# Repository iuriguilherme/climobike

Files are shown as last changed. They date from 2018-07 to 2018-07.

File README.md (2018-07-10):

ClimoBike
===

ClimoBike é uma central de monitoramento portátil da qualidade do ar e das condições climáticas, adaptável a bicicletas urbanas.  

Foto (recortada) do projeto no festival de tecnologias red bull basement  

---

Toda a documentação está na [wiki](https://op.velivery.com.br/projects/climobike/wiki).  

Projeto original: <https://github.com/smjacques/climobike>  

### Código fonte

Repositório público git:  

* <https://notabug.org/velivery/climobike>  

### Roadmap

<https://op.velivery.com.br/topics/56>

### Versões

v0.1, 2017-10-05 -- sistema de monitoramento da qualidade do ar e das condições climáticas adaptável a bicicletas, <https://github.com/smjacques/climobike>  
v0.2, 2018-06-10 -- ClimoBike + Velivery <https://notabug.org/velivery/climobike>  
v0.2.0.1, 2018-06-30 -- ESP32 Devkit + GPS, sensor de metano, sensor de gases tóxicos, sensor de umidade relativa do ar e temperatura  
v0.2.0.2, 2018-07-07 -- ESP32 Devkit v2 soldado em placa dentro de invólucro de acrílico com GPS, módulo de cartão SD, sensor de metano, sensor de gases tóxicos, sensor de dióxido de carbono, sensor de umidade relativa do ar e temperatura, buzzer, relógio, e sensor de luminosidade   

Licença
---

Copyleft 2017 Saulo Jacques  
Copyleft 2018 Velivery  

### Contribuições

- Saulo Jacques  
- Alisson Claudino  
- Desobediente Civil  

### GPL v3

**Este programa é distribuído na esperança de que possa ser útil,**
**mas SEM NENHUMA GARANTIA; sem uma garantia implícita de ADEQUAÇÃO**  
**a qualquer MERCADO ou APLICAÇÃO EM PARTICULAR. Veja a**  
**Licença Pública Geral GNU para mais detalhes.**  

**Você deve ter recebido uma cópia da Licença Pública Geral GNU junto**  
**com este programa (veja o arquivo LICENSE.md).**  
**Se não, veja <http://www.gnu.org/licenses/>.**

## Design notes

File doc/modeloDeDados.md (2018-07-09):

# Modelo de dados

Este arquivo é um modelo de como os dados devem ser armazenados no cartão SD

## Nomenclatura de arquivos

Para o ClimoBike 0.2.1, o minuto obtido do relógio deve determinar o nome do 
arquivo. Em caso de falha, um novo arquivo deve ser criado. Em caso de sucesso 
e contínua obtenção de dados, a cada hora um novo arquivo deverá ser criado.
Exemplo do sistema de arquivos em um caso onde às 18:17 um climobike foi 
ligado, sendo que às 18:23 aconteceu uma falha com o cartão, o climobike se 
recuperou e continuou gravando, funcionando normalmente até às 23:45 do mesmo 
dia:

    /dados/2018-07-03-18-17.txt
    /dados/2018-07-03-18-23.txt
    /dados/2018-07-03-18-33.txt
    /dados/2018-07-03-19-33.txt
    /dados/2018-07-03-20-33.txt
    /dados/2018-07-03-21-33.txt
    /dados/2018-07-03-22-33.txt
    /dados/2018-07-03-23-33.txt

Para o ClimoBike 0.2.2, desejavelmente a rotação do arquivo deve ser diária. 
Então o mesmo exemplo acima teria o seguinte resultado se ficasse rodando a 
semana toda:

    /dados/2018-07-03-18-17.txt
    /dados/2018-07-03-18-23.txt
    /dados/2018-07-03-18-33.txt
    /dados/2018-07-04-18-33.txt
    /dados/2018-07-05-18-33.txt
    /dados/2018-07-06-18-33.txt
    /dados/2018-07-07-18-33.txt

## Armazenamento

Os dados devem ser gravados em um arquivo no cartão SD conforme o padrão 
supracitado, de linha em linha e em formato de dicionário python de acordo com 
o padrão JSON.
Abaixo um exemplo identado para facilitar a compreensão, mas nos arquivos, 
todos dados devem estar em uma única linha, que deve ser gravada com somente o 
último caractere sendo newline.

    {
      "climobike" : "0.2.0.2",
      "json" : "0.2",
      "datetime" : "2018-07-03 18:00",
      "tmp" : "25.0",
      "hum" : "50.0",
      "ch4" : "4096",
      "tox" : "4096",
      "co2" : "4096",
      "gpsdate" : "2018-07-03 18:00:00:00",
      "gpslat" : "-30.04",
      "gpslng" : "-51.22",
      "gpssat" : "5",
      "gpshdop" : "535",
    }

Como deveria aparecer em um arquivo gravado no cartão microsd, para garantir a
consistência da escrita, leitura, e envio para servidores HTTP remotos,
assumindo uma gravação em arquivo hipotética com intervalo de um minuto:

    {"climobike":"0.2.0.2","json":"0.2","datetime":"2018-07-03 18:00","tmp":"25.0","hum":"50.0","ch4":"4096","tox":"4096","co2":"4096","gpsdate":"2018-07-03 18:00:00:00","gpslat":"-30.04","gpslng":"-51.22","gpssat":"5","gpshdop":"535",}
    {"climobike":"0.2.0.2","json":"0.2","datetime":"2018-07-03 18:01","tmp":"25.1","hum":"49.9","ch4":"4095","tox":"4097","co2":"4098","gpsdate":"2018-07-03 18:01:00:00","gpslat":"-30.04","gpslng":"-51.22","gpssat":"5","gpshdop":"535",}
    {"climobike":"0.2.0.2","json":"0.2","datetime":"2018-07-03 18:02","tmp":"25.4","hum":"49.9","ch4":"4099","tox":"4092","co2":"4094","gpsdate":"2018-07-03 18:02:00:00","gpslat":"-30.04","gpslng":"-51.22","gpssat":"5","gpshdop":"535",}
    {"climobike":"0.2.0.2","json":"0.2","datetime":"2018-07-03 18:03","tmp":"25.5","hum":"50.1","ch4":"4095","tox":"4093","co2":"4088","gpsdate":"2018-07-03 18:03:00:00","gpslat":"-30.04","gpslng":"-51.22","gpssat":"5","gpshdop":"535",}
    {"climobike":"0.2.0.2","json":"0.2","datetime":"2018-07-03 18:04","tmp":"25.4","hum":"50.3","ch4":"4094","tox":"4096","co2":"4090","gpsdate":"2018-07-03 18:04:00:00","gpslat":"-30.04","gpslng":"-51.22","gpssat":"5","gpshdop":"535",}

### Legenda

- "climobike" : String, versão do ClimoBike;
- "json" : String, versão do modelo de dados;
- "datetime" : RTCDateTime, dados do DS1307;
- "tmp" : Float, temperatura em graus Celsius do DHT;
- "hum" : Float, umidade relativa do ar em (formato) do DHT;
- "ch4" : Float, (quantidade) de metano em (formato) do sensor MQ4;
- "tox" : Float, (quantidade) de gases tóxicos em (formato) do sensor MQ135;
- "co2" : Float, (quantidade) de monóxido de carbono em (formato) do sensor MQ7;
- "gpsdate" : Datetime, dados do GPS (modelo);
- "gpslat" : Float, latitude, dados do GPS;
- "gpslng" : Float, longitude, dados do GPS;
- "gpssat" : Int, quantidade de satélites, dados do GPS;
- "gpshdop" : Int, HDOP, dados do GPS;

## API

Todos sistemas que usufruirem dos dados do climobike terão que respeitar o 
formato definido neste documento. Preferivelmente adaptar radicalmente o 
formato somente até a versão de produção do ClimoBike 0.2

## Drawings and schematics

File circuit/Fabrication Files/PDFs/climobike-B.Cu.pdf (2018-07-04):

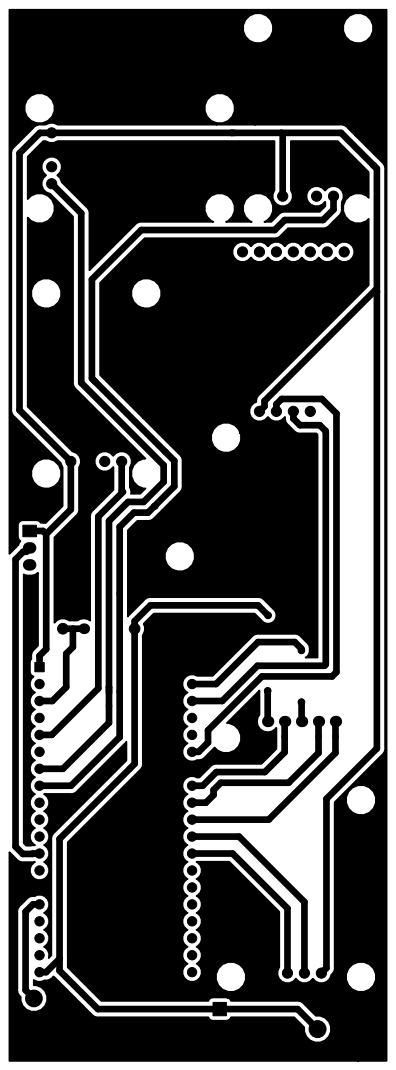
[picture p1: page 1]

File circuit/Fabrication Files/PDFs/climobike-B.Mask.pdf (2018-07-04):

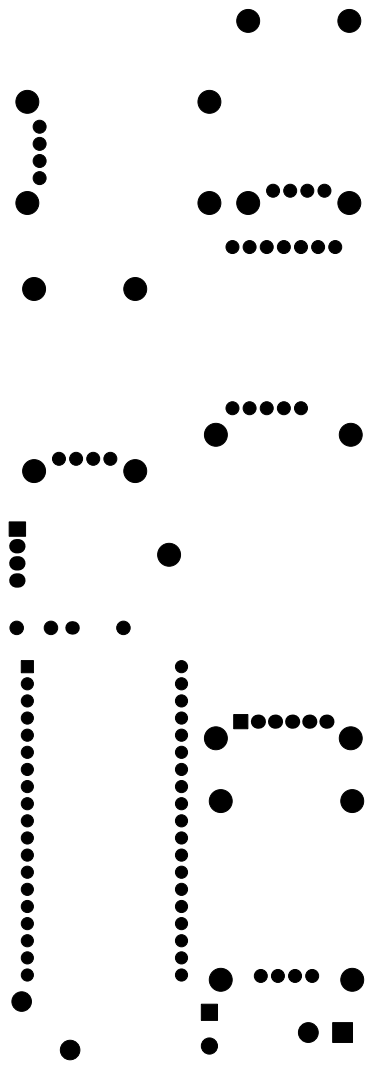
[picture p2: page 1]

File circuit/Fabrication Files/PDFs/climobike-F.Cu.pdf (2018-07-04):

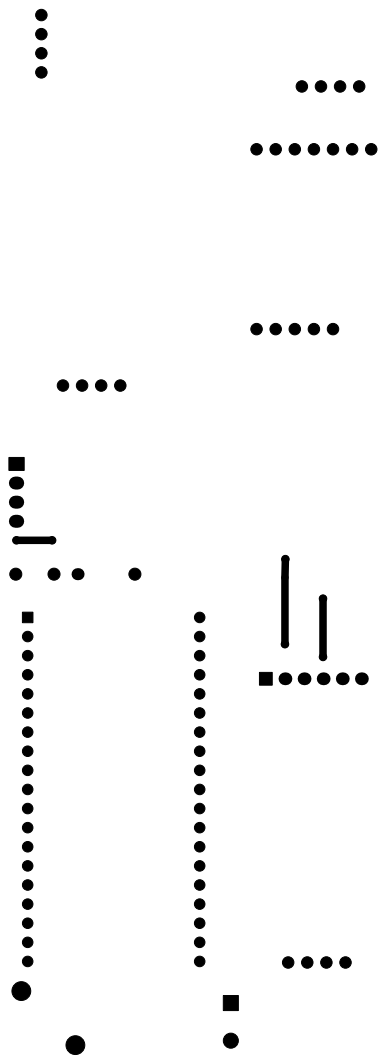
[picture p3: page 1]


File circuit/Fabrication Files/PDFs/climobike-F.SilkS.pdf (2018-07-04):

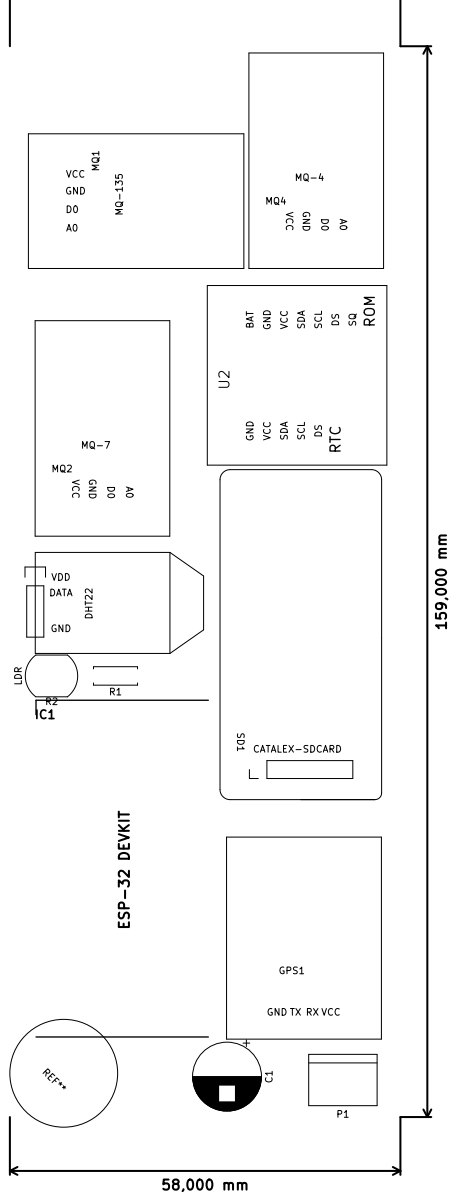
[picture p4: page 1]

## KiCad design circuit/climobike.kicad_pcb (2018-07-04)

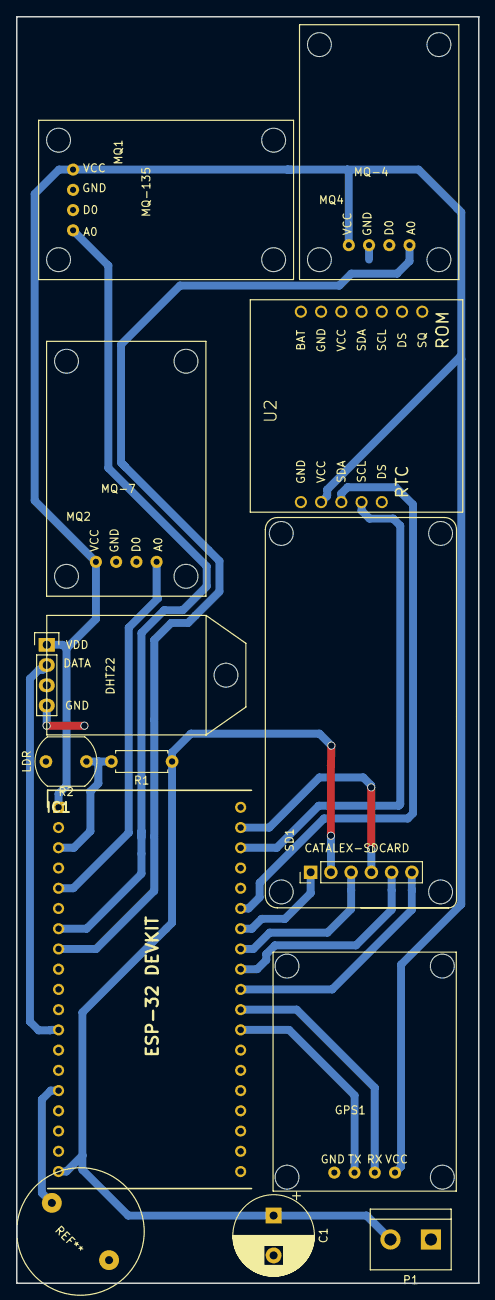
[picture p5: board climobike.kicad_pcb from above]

Board: 2 copper layers, 58.0 x 159.0 mm, 12 parts (0 on the bottom side), 16 nets.

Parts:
C1: 1000u; CP_Radial_D10.0mm_P5.00mm
GPS1: NEO-6M; Ublox-NEO-6M
IC1: ESP32-DevKitC; ESP32-DEVKIT-C
MQ1: MQ-135; MQ-Sensor
MQ2: MQ-7; MQ-Sensor
MQ4: MQ-4; MQ-Sensor
P1: INPUT; bornier2
R1: R_SHUNT; R_Axial_DIN0207_L6.3mm_D2.5mm_P7.62mm_Horizontal
R2: LDR; R_LDR_7x6mm_P5.1mm_Vertical
SD1: U_SDCARD; CATALEX-SDCARD
U1: DHT22; DHT22_Temperature_Humidity
U2: Tiny_RTC_DS1307

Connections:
+3V3: GPS1.4, IC1.1, MQ1.4, MQ2.4, MQ4.4, U1.1, U2.9
CLOCK_SCL: IC1.36, U2.11
CLOCK_SDA: IC1.33, U2.10
CO_OUT: IC1.5, MQ2.1
DHT_PIN: IC1.12, U1.2
GND: C1.2, GPS1.1, IC1.14, IC1.32, IC1.38, MQ1.3, MQ2.3, MQ4.3, P1.1, R2.2, SD1.6, U1.4, U2.8
GPS_RX: GPS1.3, IC1.28
GPS_TX: GPS1.2, IC1.27
LDR_V: IC1.3, R1.2, R2.1
MET_OUT: IC1.8, MQ4.1
SD_CLK: IC1.30, SD1.2
SD_CS: IC1.29, SD1.1
SD_MISO: IC1.31, SD1.4
SD_MOSI: IC1.37, SD1.3
TOX_OUT: IC1.7, MQ1.1
VCC: C1.1, IC1.19, P1.2, R1.1, SD1.5

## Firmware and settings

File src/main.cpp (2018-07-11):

/*
 *  ClimoBike v0.2.0.2
 *  Board:  esp32dev (v1, v2)
 *  Authors:
 *    Alisson Claudino (https://inf.ufrgs.br/~acjesus)
 *    Desobediente Civil (https://notabug.org/desci)
 *  License:  GNU GPLv3
 *
 * Este programa é distribuído na esperança de que possa ser útil,
 * mas SEM NENHUMA GARANTIA; sem uma garantia implícita de ADEQUAÇÃO a qualquer
 * MERCADO ou APLICAÇÃO EM PARTICULAR. Veja a Licença Pública Geral GNU
 * para mais detalhes.
 *
 * Você deve ter recebido uma cópia da Licença Pública Geral GNU junto
 * com este programa (veja o arquivo LICENSE.md).
 * Se não, veja http://www.gnu.org/licenses/.
*/

#if defined(ARDUINO) && ARDUINO >= 100
#include "Arduino.h"
#else
#include "WProgram.h"
#endif

#include <climobike/SdCard.hpp>
//#include <climobike/climobikeLog.hpp>
#include <climobike/climobikeBluetooth.hpp>
#include <climobike/ClimobikeWiFi.hpp>
#include <climobike/climobikeHttp.hpp>
#include <climobike/ClimobikeGPS.hpp>
#include <climobike/climobikeAnal.hpp>
#include <climobike/climobikeDht.hpp>
#include <climobike/climobikeMario.hpp>

/* depende de Log */

/* depende de Log */

/*
 *  depende de Log, Bluetooth, Wifi, Gps, Anal, Dht, Relogio, Persistencia, 
 *  Mario
*/
#include <climobike/climobikeTestes.hpp>

void setup(){
  delay(1000);
  Serial.begin(9600);

//  setupAnal();
//  setupBluetooth();
//  setupRelogio();
//  setupDht();
//  setupWifi();
//  setupSd();
//  setupHttp();
//  setupGps();

//  setupTeste0();
  setupTeste1();
//  setupTeste2();
//  setupTeste3();
//  setupTeste4();
//  setupTeste5();
}

void loop() {
//  loopTeste0();
  loopTeste1();
//  loopTeste2();
//  loopTeste3();
//  loopTeste4();
//  loopTeste5();
}

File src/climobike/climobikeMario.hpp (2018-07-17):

/* Arduino Mario Bros Tunes With Piezo Buzzer and PWM

             by : ARDUTECH
  Connect the positive side of the Buzzer to pin 3,
  then the negative side to a 1k ohm resistor. Connect
  the other side of the 1 k ohm resistor to
  ground(GND) pin on the Arduino.
  */
/*
 *  Alterado para operar no protótipo do ClimoBike
 *  Authors:
 *    Alisson Claudino (https://inf.ufrgs.br/~acjesus)
 *    Desobediente Civil (https://notabug.org/desci)
 *  License: CC0
 *  TODO: Acrescentar CC0 nos arquivos de licença
*/

#ifndef CLIMOBIKEMARIO_H
#define CLIMOBIKEMARIO_H

#if defined(ARDUINO) && ARDUINO >= 100
#include "Arduino.h"
#else
#include "WProgram.h"
#endif

#define NOTE_B0  31
#define NOTE_C1  33
#define NOTE_CS1 35
#define NOTE_D1  37
#define NOTE_DS1 39
#define NOTE_E1  41
#define NOTE_F1  44
#define NOTE_FS1 46
#define NOTE_G1  49
#define NOTE_GS1 52
#define NOTE_A1  55
#define NOTE_AS1 58
#define NOTE_B1  62
#define NOTE_C2  65
#define NOTE_CS2 69
#define NOTE_D2  73
#define NOTE_DS2 78
#define NOTE_E2  82
#define NOTE_F2  87
#define NOTE_FS2 93
#define NOTE_G2  98
#define NOTE_GS2 104
#define NOTE_A2  110
#define NOTE_AS2 117
#define NOTE_B2  123
#define NOTE_C3  131
#define NOTE_CS3 139
#define NOTE_D3  147
#define NOTE_DS3 156
#define NOTE_E3  165
#define NOTE_F3  175
#define NOTE_FS3 185
#define NOTE_G3  196
#define NOTE_GS3 208
#define NOTE_A3  220
#define NOTE_AS3 233
#define NOTE_B3  247
#define NOTE_C4  262
#define NOTE_CS4 277
#define NOTE_D4  294
#define NOTE_DS4 311
#define NOTE_E4  330
#define NOTE_F4  349
#define NOTE_FS4 370
#define NOTE_G4  392
#define NOTE_GS4 415
#define NOTE_A4  440
#define NOTE_AS4 466
#define NOTE_B4  494
#define NOTE_C5  523
#define NOTE_CS5 554
#define NOTE_D5  587
#define NOTE_DS5 622
#define NOTE_E5  659
#define NOTE_F5  698
#define NOTE_FS5 740
#define NOTE_G5  784
#define NOTE_GS5 831
#define NOTE_A5  880
#define NOTE_AS5 932
#define NOTE_B5  988
#define NOTE_C6  1047
#define NOTE_CS6 1109
#define NOTE_D6  1175
#define NOTE_DS6 1245
#define NOTE_E6  1319
#define NOTE_F6  1397
#define NOTE_FS6 1480
#define NOTE_G6  1568
#define NOTE_GS6 1661
#define NOTE_A6  1760
#define NOTE_AS6 1865
#define NOTE_B6  1976
#define NOTE_C7  2093
#define NOTE_CS7 2217
#define NOTE_D7  2349
#define NOTE_DS7 2489
#define NOTE_E7  2637
#define NOTE_F7  2794
#define NOTE_FS7 2960
#define NOTE_G7  3136
#define NOTE_GS7 3322
#define NOTE_A7  3520
#define NOTE_AS7 3729
#define NOTE_B7  3951
#define NOTE_C8  4186
#define NOTE_CS8 4435
#define NOTE_D8  4699
#define NOTE_DS8 4978

#define melodyPin 13
//Mario main theme melody
int melody[] = {
  NOTE_E7, NOTE_E7, 0, NOTE_E7,
  0, NOTE_C7, NOTE_E7, 0,
  NOTE_G7, 0, 0,  0,
  NOTE_G6, 0, 0, 0,

  NOTE_C7, 0, 0, NOTE_G6,
  0, 0, NOTE_E6, 0,
  0, NOTE_A6, 0, NOTE_B6,
  0, NOTE_AS6, NOTE_A6, 0,

  NOTE_G6, NOTE_E7, NOTE_G7,
  NOTE_A7, 0, NOTE_F7, NOTE_G7,
  0, NOTE_E7, 0, NOTE_C7,
  NOTE_D7, NOTE_B6, 0, 0,

  NOTE_C7, 0, 0, NOTE_G6,
  0, 0, NOTE_E6, 0,
  0, NOTE_A6, 0, NOTE_B6,
  0, NOTE_AS6, NOTE_A6, 0,

  NOTE_G6, NOTE_E7, NOTE_G7,
  NOTE_A7, 0, NOTE_F7, NOTE_G7,
  0, NOTE_E7, 0, NOTE_C7,
  NOTE_D7, NOTE_B6, 0, 0
};
//Mario main them tempo
int tempo[] = {
  12, 12, 12, 12,
  12, 12, 12, 12,
  12, 12, 12, 12,
  12, 12, 12, 12,

  12, 12, 12, 12,
  12, 12, 12, 12,
  12, 12, 12, 12,
  12, 12, 12, 12,

  9, 9, 9,
  12, 12, 12, 12,
  12, 12, 12, 12,
  12, 12, 12, 12,

  12, 12, 12, 12,
  12, 12, 12, 12,
  12, 12, 12, 12,
  12, 12, 12, 12,

  9, 9, 9,
  12, 12, 12, 12,
  12, 12, 12, 12,
  12, 12, 12, 12,
};
//Underworld melody
int testMelody[] =
{
  NOTE_C4, NOTE_C5, NOTE_A3, NOTE_A4,
  NOTE_AS3, NOTE_AS4, 0
};
int testMelody_tempo[] =
{
  12, 12, 12, 12,
  12, 12, 6,
};

int underworld_melody[] = {
  NOTE_C4, NOTE_C5, NOTE_A3, NOTE_A4,
  NOTE_AS3, NOTE_AS4, 0,
  0,
  NOTE_C4, NOTE_C5, NOTE_A3, NOTE_A4,
  NOTE_AS3, NOTE_AS4, 0,
  0,
  NOTE_F3, NOTE_F4, NOTE_D3, NOTE_D4,
  NOTE_DS3, NOTE_DS4, 0,
  0,
  NOTE_F3, NOTE_F4, NOTE_D3, NOTE_D4,
  NOTE_DS3, NOTE_DS4, 0,
  0, NOTE_DS4, NOTE_CS4, NOTE_D4,
  NOTE_CS4, NOTE_DS4,
  NOTE_DS4, NOTE_GS3,
  NOTE_G3, NOTE_CS4,
  NOTE_C4, NOTE_FS4, NOTE_F4, NOTE_E3, NOTE_AS4, NOTE_A4,
  NOTE_GS4, NOTE_DS4, NOTE_B3,
  NOTE_AS3, NOTE_A3, NOTE_GS3,
  0, 0, 0
};
//Underwolrd tempo
int underworld_tempo[] = {
  12, 12, 12, 12,
  12, 12, 6,
  3,
  12, 12, 12, 12,
  12, 12, 6,
  3,
  12, 12, 12, 12,
  12, 12, 6,
  3,
  12, 12, 12, 12,
  12, 12, 6,
  6, 18, 18, 18,
  6, 6,
  6, 6,
  6, 6,
  18, 18, 18, 18, 18, 18,
  10, 10, 10,
  10, 10, 10,
  3, 3, 3
};
void buzz(int targetPin, long frequency, long length);

int song = 0;

void tocaGPS()
{
  int size = sizeof(testMelody) / sizeof(int);
  for (int thisNote = 0; thisNote < size; thisNote++) {

    // to calculate the note duration, take one second
    // divided by the note type.
    //e.g. quarter note = 1000 / 4, eighth note = 1000/8, etc.
    int noteDuration = 1000 / testMelody_tempo[thisNote];

    buzz(melodyPin, testMelody[thisNote], noteDuration);

    // to distinguish the notes, set a minimum time between them.
    // the note's duration + 30% seems to work well:
    int pauseBetweenNotes = noteDuration * 1.30;
    delay(pauseBetweenNotes);

    // stop the tone playing:
    buzz(melodyPin, 1, noteDuration);
  }
}

void sing(int s) {
  // iterate over the notes of the melody:
  song = s;
  if (song == 2) {
    Serial.println(" 'Underworld Theme'");
    int size = sizeof(underworld_melody) / sizeof(int);
    for (int thisNote = 0; thisNote < size; thisNote++) {

      // to calculate the note duration, take one second
      // divided by the note type.
      //e.g. quarter note = 1000 / 4, eighth note = 1000/8, etc.
      int noteDuration = 1000 / underworld_tempo[thisNote];

      buzz(melodyPin, underworld_melody[thisNote], noteDuration);

      // to distinguish the notes, set a minimum time between them.
      // the note's duration + 30% seems to work well:
      int pauseBetweenNotes = noteDuration * 1.30;
      delay(pauseBetweenNotes);

      // stop the tone playing:
      buzz(melodyPin, 1, noteDuration);

    }

  } else {

    Serial.println(" 'Mario Theme'");
    int size = sizeof(melody) / sizeof(int);
    for (int thisNote = 0; thisNote < size; thisNote++) {

      // to calculate the note duration, take one second
      // divided by the note type.
      //e.g. quarter note = 1000 / 4, eighth note = 1000/8, etc.
      int noteDuration = 1000 / tempo[thisNote];

      buzz(melodyPin, melody[thisNote], noteDuration);

      // to distinguish the notes, set a minimum time between them.
      // the note's duration + 30% seems to work well:
      int pauseBetweenNotes = noteDuration * 1.30;
      delay(pauseBetweenNotes);

      // stop the tone playing:
      buzz(melodyPin, 0, noteDuration);

    }
  }
}
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

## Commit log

2018-06-19 ADD: ESP32 raw code + Wifi Connect
2018-06-27 ADD: Sdcard + Clock + Sensors + Wifi complete configure
2018-06-27 ADD: pin map
2018-06-28 Porra de platformio init
2018-06-28 Mais arrumacao de codigo
2018-06-30 ADD: Other Sensors MAP+Code
2018-06-30 ADD: Circuit Schematic + KiCad Libs
    [climobike.kicad_pcb, climobike.sch]
2018-06-30 Removidas mensagens de DEBUG
2018-07-02 Enviando testes para repositório
2018-07-03 Versão GPS funcionando de fato
2018-07-03 ADD: Full circuit schematic and pcb design
    [climobike.kicad_pcb, climobike.sch]
2018-07-03 Fiz um gráfico de LDR em python
2018-07-03 Consertando erros de compilação
2018-07-03 Ligando sensores de gás e dht
2018-07-04 -"Putz cara, como é que tu faz uma coisa dessa"
2018-07-04 Pressa de trollar da nisso
2018-07-04 Testando Wire transmission
2018-07-04 Abortando o teste de gravação e retornando ao teste1
2018-07-04 ADD: Fabrication files
    [climobike.kicad_pcb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]
2018-07-04 Modelo de dados v0.2
2018-07-04 Copiando o código inteiro para o teste
2018-07-04 Corrigindo erros de compilação
2018-07-04 Preparando para o sucesso
2018-07-04 Próximo passo para o teste 2
2018-07-06 Enviando para produção
2018-07-08 Introduzindo dados falsos para teste
